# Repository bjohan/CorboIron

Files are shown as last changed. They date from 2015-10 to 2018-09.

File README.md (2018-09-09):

# CorboIron
With stand taken off
Soldering station with one pencil holder on bench.

Soldering station front view
Soldering station with both pencil holders hanging.

Soldering station side view
Side view

Front view again
Front view

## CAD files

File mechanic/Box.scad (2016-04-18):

module powerSupply()
{
    cube([200, 100, 42]);
}

module bottomHousing(ix, iy, iz, t)
{
    difference(){
        translate([-t,-t,-t])
            cube([ix+2*t, iy+2*t, iz+t]);
    
        cube([ix, iy, iz+1]);
    }
}

module iecHoles(t)
{
    hs = 55.5-3.5;
    lc = 23;
    
    rotate(-90, [0, 0, 1]){
    translate([0, lc-hs/2, 10])
        rotate(90,[0,1,0])
            cylinder(t, 3/2,3/2, $fn=10);
    translate([0, lc+hs/2, 10])
        rotate(90,[0,1,0])
            cylinder(t, 3/2,3/2, $fn=10);
    translate()
        cube([t, 46, 20]);
    }
}

module fanHoles(t)
{
    
    //translate([0, lc-hs/2, 10])
        rotate(90,[1,0,0]){
            cylinder(t, 24,24);
            translate([20, 20, 0])
                cylinder(t, 3/2, 3/2, $fn=10);
            translate([20, -20, 0])
                cylinder(t, 3/2, 3/2, $fn=10);
            translate([-20, 20, 0])
                cylinder(t, 3/2, 3/2, $fn=10);
            translate([-20, -20, 0])
                cylinder(t, 3/2, 3/2, $fn=10);
        }
}


module exhaustHoles(t)
{
    r = 2.5;
    sep = 10;
    for(x = [0:5])
        for (z = [0:2]){
            translate([x*sep, 0, z*sep])
                rotate(90,[1,0,0])
                    cylinder(t, r, r);
        }
        /*rotate(90,[1,0,0]){
            cylinder(t, 24,24);
            translate([20, 20, 0])
                cylinder(t, 3/2, 3/2);
            translate([20, -20, 0])
                cylinder(t, 3/2, 3/2);
            translate([-20, 20, 0])
                cylinder(t, 3/2, 3/2);
            translate([-20, -20, 0])
                cylinder(t, 3/2, 3/2);
        }*/
}



module bottomSectionHoles(ix, iy, iz, t,r){
    translate([-t-1, 10, iz-5])
        rotate(90, [0, 1, 0] )
            cylinder(ix+2*t+2, r);
    
    translate([-t-1, iy+2*t-10, iz-5])
        rotate(90, [0, 1, 0] )
            cylinder(ix+2*t+2, r);
    
    translate([-t-1, (iy+2*t)/2, iz-5])
        rotate(90, [0, 1, 0] )
            cylinder(ix+2*t+2, r);
}


module bottomSection(ix, iy, iz, t){ 
    difference(){
        bottomHousing(ix, iy, iz,t);
        translate([ix-30, iy+2*t-1, 24+2])
            fanHoles(6);
        translate([ix-120, iy+2*t-1, 0])
            iecHoles(6);
        translate([10, 1, 10])
            exhaustHoles(5, $fn=10);
         translate([ix-135, -4, -t]){
             displayCavity(55, 55, 135+t, t, 6);    
         }
         
          translate([75, -40, 5])
            rotate(45,[1,0,0]) 
                       translate([0,0,0])
            displayHoles(10, 3);
         
         
        /*translate([-3, 10, 40])
            iecHoles(3);
        translate([-4, 85, 60])
            fanHoles(6);*/
         bottomSectionHoles(ix, iy, iz, t, 3/2, $fn=10);

    }
   
   difference(){ 
    translate([ix-135, 0, -t]){
        displaySection(55, 55, 135+t, t);
    }
    
    translate([75, -40, 5])
        rotate(45,[1,0,0]){ 
            display();
            translate([0,0,0])
            displayHoles(10, 3/2);
            translate([115, 30, 0])
            cylinder(10, 7/2, 7/2);
        }
         translate([ix-135-1, -60, -3])
            cube([135+t+2,15,100]);
    }
    translate([ix-135, -45, -t])
            cube([135+t,t,10]);
   
}


module displayHoles(t, r)
{
    $fn = 10;
    y = 55;
    x = 93;
    xo = (98-x)/2;
    yo = (60-y)/2;
    translate( [xo,yo, 0])
        cylinder(t, r, r);
    translate( [xo+x,yo, 0])
        cylinder(t, r, r);
    translate( [xo+x,yo+y, 0])
        cylinder(t, r, r);
    translate( [xo,yo+y, 0])
        cylinder(t, r, r);
}

module displayVolumes(){
    cube([98, 60, 2]);
    translate([0, 10, -2])
        cube([98, 40, 14]);
    translate([8, 60-22, -12])
        cube([52, 22, 12]);
}


module displaySection(ox, oy,oz, t)
{
    oPoints = [[0, 0], [ox, 0], [0, oy]];
    iPoints = [[t, 0], [ox-t, 0], [t, oy-2*t]];
    rotate(180, [0, 0, 1])
    rotate(-90, [0, 1, 0])
    difference(){
        linear_extrude(oz)
            polygon(oPoints);
    
        translate([0,0,t])
            linear_extrude(oz-2*t)
                polygon(iPoints);
    }
}

module displayCavity(ox, oy, oz, td, t)
{
    x = ox-2*td;
    y = oy -2*td;
    z = oz -2*td;
    translate([td, 0, td])
    cube([z,t, x]);
}


module display()
{
    difference(){
        displayVolumes();
        translate([0,0,-1])
        displayHoles(5);
    }
    
}


module pcb(){
    cube([160, 100, 2]);
    translate([-20, 4, 2])
        cube([20, 92, 17]);
}

module topHousing(ix, iy, iz, t, tol, overlap, height){
 translate([t+tol/2, t+tol/2, iz-overlap+t])
    bottomHousing(ix-tol-2*t, iy-tol-2*t, overlap-t, t);
    
 translate([0, 0, iz]){
     //difference(){
        translate([tol/2, tol/2, 0]){
            difference(){
            bottomHousing(ix-tol, iy-tol, height, t+tol/2);
            translate([0,0,-t-tol])
                cube([ix-tol, iy-tol, t+tol]);
            }
        }
     //}
     translate([1,7,-8])
     difference(){
        cube([10,15,10]);
         translate([5, 5, 0])
            cylinder(10, 1.5, 1.5, $fn=10);
     }
     translate([150,7,-8])
     difference(){
        cube([15,15,10]);
         translate([7, 5, 0])
            cylinder(10, 1.5, 1.5, $fn=10);
     }
     translate([1, 100, 0]){
         translate([0,5,-8])
             difference(){
                cube([10,15,10]);
                 translate([5, 10, 0])
                    cylinder(10, 1.5, 1.5, $fn=10);
             }
         translate([150,5,-8])
             difference(){
                cube([15,15,10]);
                 translate([7, 10, 0])
                    cylinder(10, 1.5, 1.5, $fn=10);
             }
     }
 }
    }

module topSection(ix, iy, iz, t, tol, overlap, height){

    difference(){
    topHousing(ix, iy, iz, t, tol, overlap, height);
        translate([t+tol/2, t+tol/2, iz-overlap+t]){
    translate([-t,10,8]){
        pcb();
        translate([151-t-tol/2, 113+t-5, -overlap-t])
            cube([50, 20, overlap+t]);
    }
     
    }bottomSectionHoles(ix, iy, iz, t, 3/2, $fn=10);
    }
    //translate to bottom plane
    translate([t+tol/2, t+tol/2, iz-overlap+t]){
        translate([-t-tol/2,0,8]){
            //pcb();
        }
        translate([-t*2-tol/2, -t*2-tol/2, -t])
            difference(){
                cube([ix+t*2, iy+t*2, overlap+t]);
                    translate([0.5, 0.5, 0])
                        cube([ix+t*2-1, iy+t*2-1, overlap+t]);
            }
    }
    
}


//displayHoles(20, 3/2);
ix = 201;
iy = 145;
iz = 55;
t = 3;
tol = 1;
overlap = 10;
height = 20;

//bottomSection(ix, iy, iz, t);
topSection(ix, iy, iz, t, tol, overlap, height);
module bottomSupports(){
translate([100, -8, 0])
cylinder(42.2,3,3);
translate([140, -8, 0])
cylinder(42.2,3,3);
translate([105, iy, 0])
cylinder(19.9,3,3);
}
//translate([75, -40, 5])
//        rotate(45,[1,0,0]) 
//            display();

//translate([-3, 10, 40])
//        iecHoles(3);
//translate([-4, iy+2*t, 60])
//        fanHoles(6);
//translate([0,15,0])
//    powerSupply();

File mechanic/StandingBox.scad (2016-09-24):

//$fn=200;
mainHousingInsideX = 120;
mainHousingInsideY = 120;
mainHousingInsideZ = 210;
t = 3;

dispTiltOffs = 20;
dispProjHeight = 50;
dispRecess = 40;
topFoldHeight = 20;

module powerSupply()
{
    cube([200, 100, 42]);
}

module iecHoles(t)
{
    hs = 55.5-3.5;
    lc = 23;
    
    rotate(-90, [0, 0, 1]){
    translate([0, lc-hs/2, 10])
        rotate(90,[0,1,0])
            cylinder(t, 3/2,3/2, $fn=10);
    translate([0, lc+hs/2, 10])
        rotate(90,[0,1,0])
            cylinder(t, 3/2,3/2, $fn=10);
    translate()
        cube([t, 46, 20]);
    }
}

module fanHoles(t)
{
    
    //translate([0, lc-hs/2, 10])
        rotate(90,[1,0,0]){
            cylinder(t, 24,24);
            translate([20, 20, 0])
                cylinder(t, 3/2, 3/2, $fn=10);
            translate([20, -20, 0])
                cylinder(t, 3/2, 3/2, $fn=10);
            translate([-20, 20, 0])
                cylinder(t, 3/2, 3/2, $fn=10);
            translate([-20, -20, 0])
                cylinder(t, 3/2, 3/2, $fn=10);
        }
}


module displayHoles(t, r)
{
    $fn = 10;
    y = 55;
    x = 93;
    xo = (98-x)/2;
    yo = (60-y)/2;
    translate( [xo,yo, 0])
        cylinder(t, r, r);
    translate( [xo+x,yo, 0])
        cylinder(t, r, r);
    translate( [xo+x,yo+y, 0])
        cylinder(t, r, r);
    translate( [xo,yo+y, 0])
        cylinder(t, r, r);
}

module displayVolumes(){
    cube([98, 60, 2]);
    translate([0, 10, -2])
        cube([98, 40, 14]);
    translate([8, 60-22, -12])
        cube([52, 22, 12]);
}




module display()
{
    difference(){
        displayVolumes();
        translate([0,0,-1])
        displayHoles(5);
    }
    
}


module pcb(){
    cube([160, 100, 2]);
    translate([-20, 4, 2])
        cube([20, 92, 17]);
}

module mainHousing(sx, sy, sz, t){
    fanHoleY=70;
    fanHoleZ=30;
    exhaustSeparation = 10;
    difference(){
        cube([sx, sy, sz]);
        translate([t, t, t])
            cube([sx-2*t, sy-t+1, sz-2*t]);
        translate([sx/2, sy/2+10, sz+1])
            rotate([90, 0, 0])
                fanHoles(t+2);    
        for(n = [0:15]){
            translate([sx-t-1, 20+t, 20+t+exhaustSeparation*n])
                rotate([0, 90, 0])
                    cylinder(t+2, 2.5, 2.5);
        }
    }
    
}

module mainHousingFrontPanelScrewHoles(sx, sy, sz, t){
    translate([t+10, sy+t, t+5]){
        for(n = [0:5]){
            translate([20*n, 0, 0])
                rotate([90, 0, 0])
                    cylinder(25, 1.5, 1.5);
        }
    }
    
        translate([t+10, sy+t, sz-t-5]){
        for(n = [0:5]){
            translate([20*n, 0, 0])
                rotate([90, 0, 0])
                    cylinder(25, 1.5, 1.5);
        }
    }
}


module mainHousingWithFrontPanelHoles(sx, sy, sz, t){
    difference(){
        union(){
            mainHousing(sx, sy, sz, t);
            translate([t, sy-10-t, t])
                cube([sx-2*t, 10,10]);
            translate([t, sy-10-t, sz-10-t])
                cube([sx-2*t, 10,10]);
            
        }
        mainHousingFrontPanelScrewHoles(sx, sy, sz, t);
    }
}

function getDispAngle() =
    atan2(dispProjHeight, dispRecess);

module frontPanelOnSide(height, width, t){
    //dispTiltOffs = 10;
    //dispProjHeight = 50;
    //dispRecess = 30;
    //topFoldHeight = 20;http://www.di.se/artiklar/2016/6/5/schweiz-rostar-om-medborgarlon/
    dto = dispTiltOffs;
    poly = [    [0,0],
                [dispTiltOffs,0],
                [dispProjHeight+dto,dispRecess],
                //[height,dispRecess],
                [height-topFoldHeight, dispRecess],
                [height-topFoldHeight, 0],
                [height, 0],
                [height, t],
                [height-topFoldHeight+t, t],
                
                [height-topFoldHeight+t,dispRecess+t],
    
                //[height,dispRecess+t],
                [dispProjHeight+dto,dispRecess+t],
                [dispTiltOffs,+t],
                [0,t]];
    linear_extrude(width)
        polygon(points=poly);
    
}

module placedFrontPanel(height, width, depth, t){
    /*t = 3;

dispTiltOffs = 20;
dispProjHeight = 50;
dispRecess = 40;
topFoldHeight = 20;*/
    translate([t, depth+t, t])
    
    rotate([0, -90, 180]){
        frontPanelOnSide(height, width, t);
        translate([dispProjHeight+dispTiltOffs, dispRecess+t,0])
            cube([10, 10, width]);
        translate([height-topFoldHeight-10+t, dispRecess+t,0])
            cube([10, 10, width]);
    }
}

module placedDisplay(){
translate([t+(mainHousingInsideX-98)/2, 78, 68])
    rotate(-getDispAngle(),[1, 0, 0])
        rotate([0, 0, 180])
            translate([-98,-60, 0]){
                display();
               
            }
}

module placedDisplayHoles(){
translate([t+(mainHousingInsideX-98)/2, 78, 68])
    rotate(-getDispAngle(),[1, 0, 0])
        rotate([0, 0, 180])
            translate([-98,-60, 0]){
                displayHoles(10, 3/2);
            }
}
        
module placedFrontPanelWithHoles(height, width, depth, t){
    difference(){
        placedFrontPanel(height, width, depth, t);
        placedDisplay();
        placedDisplayHoles();
        mainHousingFrontPanelScrewHoles(mainHousingInsideX+2*t, mainHousingInsideY+t, mainHousingInsideZ+2*t,t);
    }
}


module placedPowerSupply(t){
    translate([t, t, t])
        rotate([0,-90,-90])
            powerSupply();
}


module penHolderMainBody(frontAngle){
    length = 110;
    height = 35;
    width = mainHousingInsideX/2;
    //frontAngle = 40;
    difference(){
    cube([width, length, height]);
    translate([0, length, 0])
        rotate([frontAngle, 0, 0])
            cube(2*[height, height, height]);
    }
}

module penHolderWithPrintHoles(angle){
    dia = 11.8;
    difference(){
        penHolderMainBody(angle);
        translate([dia, 90+2.1, dia/2])
            rotate([angle, 0, 0])
                cylinder(100 , dia/2, dia/2);
        
        translate([mainHousingInsideX/2-dia, 90+2.1, dia/2])
            rotate([angle, 0, 0])
                cylinder(100 , dia/2, dia/2);
    }
}


module penHolderDryClean(angle){
    h = 35;
    dia = 56;
    d=55;
    dt = d+h;
    angle=20;
    hd = (dia/2+2)/sqrt(2);
    difference(){
        penHolderMainBody(angle);
        
        translate([mainHousingInsideX/4, dia/2+5, 10])
            rotate([angle, 0, 0]){
                cylinder(100 , dia/2-2, dia/2-2);
                translate([0,0,13])
                    cylinder(100 , dia/2, dia/2);
                translate([hd, hd, 0])
                    cylinder(100, 3/2, 3/2);
                translate([hd, -hd, 0])
                    cylinder(100, 3/2, 3/2);
                translate([-hd, hd, 0])
                    cylinder(100, 3/2, 3/2);
                translate([-hd, -hd, 0])
                    cylinder(100, 3/2, 3/2);
                
            }

    translate([0, d, h])
        rotate([angle, 0, 0])
            translate([0, -dt, 0]){
                cube([mainHousingInsideX/2, dt, 30]);
            }

    }
    
}


module penHolder(){
  
   
    //translate([0, 0, 30])
    
    intersection(){
        penHolderDryClean(0);
        penHolderWithPrintHoles(40);
    }
}


module printFrontPanel(){
    rotate([0, 90, 0])
    placedFrontPanelWithHoles(mainHousingInsideZ, mainHousingInsideX, mainHousingInsideY, t);
    translate([10, 120, -t-2])
        cylinder(2,20,20);
    translate([210, 120, -t-2])
        cylinder(2,20,20);
    translate([80, 120-40, -t-2])
        cylinder(2,20,20);
    translate([180, 120-40, -t-2])
        cylinder(2,20,20);
}

//printFrontPanel();

/*translate([0, 120, 0])
    penHolder();

translate([0, 73, 185])
    rotate([-90,0,0])
        penHolder();*/
mainHousingWithFrontPanelHoles(mainHousingInsideX+2*t, mainHousingInsideY+t, mainHousingInsideZ+2*t,t);

placedFrontPanelWithHoles(mainHousingInsideZ, mainHousingInsideX, mainHousingInsideY, t);

//placedPowerSupply(t);

//placedDisplay();

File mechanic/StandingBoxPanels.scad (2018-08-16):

//$fn=200;
mainHousingInsideX = 120;
mainHousingInsideY = 120;
mainHousingInsideZ = 210;
t = 3;

dispTiltOffs = 20;
dispProjHeight = 50;
dispRecess = 40;
topFoldHeight = 20;


module iecHoles(t){
    hs = 55.5-3.5;
    lc = 23;
    
    rotate(-90, [0, 0, 1]){
    translate([0, lc-hs/2, 10])
        rotate(90,[0,1,0])
            cylinder(t, 3/2,3/2, $fn=10);
    translate([0, lc+hs/2, 10])
        rotate(90,[0,1,0])
            cylinder(t, 3/2,3/2, $fn=10);
    translate()
        cube([t, 46, 20]);
    }
}

module fanHoles(t){
    
    //translate([0, lc-hs/2, 10])
        //rotate(90,[1,0,0]){
            cylinder(t, 24,24);
            translate([20, 20, 0])
                cylinder(t, 3/2, 3/2, $fn=10);
            translate([20, -20, 0])
                cylinder(t, 3/2, 3/2, $fn=10);
            translate([-20, 20, 0])
                cylinder(t, 3/2, 3/2, $fn=10);
            translate([-20, -20, 0])
                cylinder(t, 3/2, 3/2, $fn=10);
        //}
}


module displayHoles(t, r){
    $fn = 10;
    y = 55;
    x = 93;
    xo = (98-x)/2;
    yo = (60-y)/2;
    translate( [xo,yo, 0])
        cylinder(t, r, r);
    translate( [xo+x,yo, 0])
        cylinder(t, r, r);
    translate( [xo+x,yo+y, 0])
        cylinder(t, r, r);
    translate( [xo,yo+y, 0])
        cylinder(t, r, r);
}

module displayVolumes(){
    cube([98, 60, 2]);
    translate([0, 10, -2])
        cube([98, 40, 14]);
    translate([8, 60-22, -12])
        cube([52, 22, 12]);
}




module display(){
    difference(){
        displayVolumes();
        translate([0,0,-1])
        displayHoles(5);
    }
    
}


module pcb(){
    cube([100, 80, 2]);
    //Iron 0 iron 1 connector
    translate([1, -5, 2])
        cube([31, 12, 11]);
    
    //Iron 2 and iron 3 connector
    translate([100-1-31, -5, 2])
        cube([31, 12, 11]);
    
    //Power in at bottom connector
    translate([43, 3, -20])
        cube([12, 25, 20]);
    
    //Filter and voltage regulator volume
    translate([37, 2, 2])
        cube([30, 30, 20]);
    
    //Arduino volume
    translate([41, 27, 2])
        cube([18, 45, 22]);
    
    //Pin headers
    translate([35, 42, 2])
        cube([3, 30, 20]);
    translate([53, 70, 2])
        cube([11, 3, 20]);
        
    //Capacitors
    translate([12, 66, 2])    
        cylinder(13,4,4);
    translate([23, 66, 2])    
        cylinder(13,4,4);
    translate([77, 66, 2])    
        cylinder(13,4,4);
    translate([89, 66, 2])    
        cylinder(13,4,4);
    
}

module mainHousing(sx, sy, sz, t){
    fanHoleY=70;
    fanHoleZ=30;
    exhaustSeparation = 10;
    difference(){
        cube([sx, sy, sz]);
        translate([t, t, t])
            cube([sx-2*t, sy-t+1, sz-2*t]);
        translate([sx/2, sy/2+10, sz+1])
            rotate([90, 0, 0])
                fanHoles(t+2);    
        for(n = [0:15]){
            translate([sx-t-1, 20+t, 20+t+exhaustSeparation*n])
                rotate([0, 90, 0])
                    cylinder(t+2, 2.5, 2.5);
        }
    }
    
}

module mainHousingFrontPanelScrewHoles(sx, sy, sz, t){
    translate([t+10, sy+t, t+5]){
        for(n = [0:5]){
            translate([20*n, 0, 0])
                rotate([90, 0, 0])
                    cylinder(25, 1.5, 1.5);
        }
    }
    
        translate([t+10, sy+t, sz-t-5]){
        for(n = [0:5]){
            translate([20*n, 0, 0])
                rotate([90, 0, 0])
                    cylinder(25, 1.5, 1.5);
        }
    }
}


module mainHousingWithFrontPanelHoles(sx, sy, sz, t){
    difference(){
        union(){
            mainHousing(sx, sy, sz, t);
            translate([t, sy-10-t, t])
                cube([sx-2*t, 10,10]);
            translate([t, sy-10-t, sz-10-t])
                cube([sx-2*t, 10,10]);
            
        }
        mainHousingFrontPanelScrewHoles(sx, sy, sz, t);
    }
}

function getDispAngle() =
    atan2(dispProjHeight, dispRecess);

module frontPanelOnSide(height, width, t){
    //dispTiltOffs = 10;
    //dispProjHeight = 50;
    //dispRecess = 30;
    //topFoldHeight = 20;http://www.di.se/artiklar/2016/6/5/schweiz-rostar-om-medborgarlon/
    dto = dispTiltOffs;
    poly = [    [0,0],
                [dispTiltOffs,0],
                [dispProjHeight+dto,dispRecess],
                //[height,dispRecess],
                [height-topFoldHeight, dispRecess],
                [height-topFoldHeight, 0],
                [height, 0],
                [height, t],
                [height-topFoldHeight+t, t],
                
                [height-topFoldHeight+t,dispRecess+t],
    
                //[height,dispRecess+t],
                [dispProjHeight+dto,dispRecess+t],
                [dispTiltOffs,+t],
                [0,t]];
    linear_extrude(width)
        polygon(points=poly);
    
}

module placedFrontPanel(height, width, depth, t){
    /*t = 3;

dispTiltOffs = 20;
dispProjHeight = 50;
dispRecess = 40;
topFoldHeight = 20;*/
    translate([t, depth+t, t])
    
    rotate([0, -90, 180]){
        frontPanelOnSide(height, width, t);
        translate([dispProjHeight+dispTiltOffs, dispRecess+t,0])
            cube([10, 10, width]);
        translate([height-topFoldHeight-10+t, dispRecess+t,0])
            cube([10, 10, width]);
    }
}

module placedDisplay(){
translate([t+(mainHousingInsideX-98)/2, 78, 68])
    rotate(-getDispAngle(),[1, 0, 0])
        rotate([0, 0, 180])
            translate([-98,-60, 0]){
                display();
               
            }
}

module placedDisplayHoles(){
translate([t+(mainHousingInsideX-98)/2, 78, 68])
    rotate(-getDispAngle(),[1, 0, 0])
        rotate([0, 0, 180])
            translate([-98,-60, 0]){
                displayHoles(10, 3/2);
            }
}
        
module placedFrontPanelWithHoles(height, width, depth, t){
    difference(){
        placedFrontPanel(height, width, depth, t);
        placedDisplay();
        placedDisplayHoles();
        mainHousingFrontPanelScrewHoles(mainHousingInsideX+2*t, mainHousingInsideY+t, mainHousingInsideZ+2*t,t);
    }
}

module powerSupply(){
    cube([200, 100, 42]);
}


module placedPowerSupply(t){
    translate([10, 10, 3+200])
        rotate([0,90,0])
            powerSupply();
}


module penHolderMainBody(frontAngle){
    length = 110;
    height = 35;
    width = (mainHousingInsideX-2)/2;
    //frontAngle = 40;
    difference(){
    cube([width, length, height]);
    translate([0, length, 0])
        rotate([frontAngle, 0, 0])
            cube(2*[height, height, height]);
    }
}

module penHolderWithPrintHoles(angle){
    dia = 11.8;
    difference(){
        penHolderMainBody(angle);
        translate([dia, 90+2.1, dia/2])
            rotate([angle, 0, 0])
                cylinder(100 , dia/2, dia/2);
        
        translate([(mainHousingInsideX-2)/2-dia, 90+2.1, dia/2])
            rotate([angle, 0, 0])
                cylinder(100 , dia/2, dia/2);
    }
}


module penHolderDryClean(angle){
    h = 35;
    dia = 56;
    d=55;
    dt = d+h;
    angle=20;
    hd = (dia/2+2)/sqrt(2);
    difference(){
        penHolderMainBody(angle);
        
        translate([(mainHousingInsideX-2)/4, dia/2+5, 10])
            rotate([angle, 0, 0]){
                cylinder(100 , dia/2-2, dia/2-2);
                translate([0,0,13])
                    cylinder(100 , dia/2, dia/2);
                translate([hd, hd, 0])
                    cylinder(100, 3/2, 3/2);
                translate([hd, -hd, 0])
                    cylinder(100, 3/2, 3/2);
                translate([-hd, hd, 0])
                    cylinder(100, 3/2, 3/2);
                translate([-hd, -hd, 0])
                    cylinder(100, 3/2, 3/2);
                
            }

    translate([0, d, h])
        rotate([angle, 0, 0])
            translate([0, -dt, 0]){
                cube([(mainHousingInsideX-2)/2, dt, 30]);
            }
    }
    
}


module penHolder(){
    intersection(){
        penHolderDryClean(0);
        penHolderWithPrintHoles(40);
    }
}


module penHolderKnob(s){
    cylinder(5, s*30/2, s*35/2);
}

module penHolderKnobKeyHole(){
    hull(){
        penHolderKnob(1);
        translate([0,10,0])
            penHolderKnob(1.3);
    }
}

module truncatedPenHolder(){
    difference(){
    penHolder();
    translate([0,100,0])
        cube([100, 20, 20]);
    translate([0,85,0])
        cube([11,15,25]);
    translate([(mainHousingInsideX-2)/2-11,85,0])
        cube([11,15,25]);
    translate([(mainHousingInsideX-2)/4,40,0])
        penHolderKnobKeyHole();
    }
}
module printFrontPanel(){
    rotate([0, 90, 0])
    placedFrontPanelWithHoles(mainHousingInsideZ, mainHousingInsideX, mainHousingInsideY, t);
    translate([10, 120, -t-2])
        cylinder(2,20,20);
    translate([210, 120, -t-2])
        cylinder(2,20,20);
    translate([80, 120-40, -t-2])
        cylinder(2,20,20);
    translate([180, 120-40, -t-2])
        cylinder(2,20,20);
}



module multiPanelp(z){
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

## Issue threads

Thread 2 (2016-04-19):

Fix ground connection in 12V zones

bjohan, 2016-04-19:
The ground does look very good in the parts of the PCB which is covered by 12V zones

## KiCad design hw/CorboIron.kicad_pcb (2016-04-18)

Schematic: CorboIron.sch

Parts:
C1, C4, C5, C6: 1uF; CV3-30PF
C2: 4u7; CV3-30PF
C3: 220u; CV3-30PF
C7, C10: 100u; CV3-30PF
C8, C9: 10n; C_1206_HandSoldering
D1, D3, D4, D5, D7, D9, D11, D12, D13, D14: D; SOD-123
D2, D6, D8, D10: LED; LED_1206
JP1, JP2: Jumper_NO_Small; Pin_Header_Straight_1x02
P1, P2, P3, P5: CONN_01X03; bornier3
P4: Arduino_nano; DIP-32_W15.24mm_LongPads
P6, P10, P11: CONN_01X04; Pin_Header_Straight_1x04
P7: CONN_01X02; bornier2
P8, P9: CONN_01X03; Pin_Header_Straight_1x03
Q1, Q2, Q3, Q4: IPS6041RPBF; DPAK5
R1, R5, R9, R13, R17, R18, R19, R20, R21, R22, R23: 100K; R_0805
R2, R6, R10, R14: 680K; R_0805
R3, R28, R29: 4k7; R_0805
R4, R8, R12, R16: 1K; R_0805
R7, R11, R15, R34, R35, R40, R41, R46, R47: 4K7; R_0805
R24, R30, R36, R42: 22K; R_0805
R25, R31, R37, R43: 6K8; R_0805
R26, R32, R38, R44: 150K; R_0805
R27, R33, R39, R45: 2K7; R_0805
R48, R49, R50, R51: 27K; R_0805
RV1, RV3, RV5, RV7: 5K; POT_SMD
U1, U2, U3, U4: LM324; SO14N
U14: 7805; TO-220_Neutral123_Vertical

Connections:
+5V: C9.1, C10.1, JP1.2, P6.1, P8.2, P9.2, P11.1, R3.1, R7.1, R11.1, R15.1, R21.1, R22.1, R23.1, R29.1, R35.1, R41.1, R47.1, U14.3 (VO)
+12V: C7.1, C8.1, JP2.1, P7.2, Q1.3 (VCC), Q2.3 (VCC), Q3.3 (VCC), Q4.3 (VCC), R1.2, R5.2, R9.2, R13.2, RV1.1, RV3.1, RV5.1, RV7.1, U1.4, U2.4, U3.4, U4.4, U14.1 (VI)
/5V_ARD: JP1.1, P4.12
/AUX0: P4.6, P8.1
/AUX1: P4.7, P9.1
/CHARGE_PUMP: C2.1, P4.29
/HTR0_CTL': D14.2 (A), U4.1
/HTR0_EN: P4.27, R42.2
/HTR1_CTL: D13.2 (A), U3.1
/HTR1_EN: P4.26, R36.2
/HTR2_CTL: D12.2 (A), U2.1
/HTR2_EN: P4.25, R30.2
/HTR3_CTL: D11.2 (A), U1.1
/HTR3_EN: P4.24, R24.2
/PUSH_SW: P4.28, P10.1, R21.2
/ROT_A: P4.22, P10.2, R22.2
/ROT_B: P4.23, P10.3, R23.2
/RX0: P4.19, P11.2
/SCL: P4.9, P6.2
/SDA: P4.8, P6.3
/TEMP0: P5.2, U4.5
/TEMP0_AMP: P4.4, R14.2, U4.7, U4.12
/TEMP0_MIN: C6.1, D9.2 (A), R13.1, U4.9, U4.13
/TEMP0_OK: D10.1 (K), R20.2, R44.2, U4.8
/TEMP1: P3.2, U3.5
/TEMP1_AMP: P4.5, R10.2, U3.7, U3.12
/TEMP1_MIN: C5.1, D7.2 (A), R9.1, U3.9, U3.13
/TEMP1_OK: D8.1 (K), R19.2, R38.2, U3.8
/TEMP2: P2.2, U2.5
/TEMP2_AMP: P4.10, R6.2, U2.7, U2.12
/TEMP2_MIN: C4.1, D5.2 (A), R5.1, U2.9, U2.13
/TEMP2_OK: D6.1 (K), R18.2, R32.2, U2.8
/TEMP3: P1.2, U1.5
/TEMP3_AMP: P4.11, R2.2, U1.7, U1.12
/TEMP3_MIN: C1.1, D1.2 (A), R1.1, U1.9, U1.13
/TEMP3_OK: D2.1 (K), R17.2, R26.2, U1.8
/TX1: P4.18, P11.3
/VIN: JP2.2, P4.15
/V_NEG: C3.2, D3.2 (A), U1.11, U2.11, U3.11, U4.11
GND: C1.2, C3.1, C4.2, C5.2, C6.2, C7.2, C8.2, C9.2, C10.2, D4.1 (K), P1.3, P2.3, P3.3, P4.14, P4.21, P5.3, P6.4, P7.1, P8.3, P9.3, P10.4, P11.4, Q1.1 (GND), Q1.4 (DG), Q2.1 (GND), Q2.4 (DG), Q3.1 (GND), Q3.4 (DG), Q4.1 (GND), Q4.4 (DG), R4.1, R8.1, R12.1, R16.1, R27.1, R28.2, R33.1, R34.2, R39.1, R40.2, R45.1, R46.2, R48.1, R49.1, R50.1, R51.1, RV1.3, RV3.3, RV5.3, RV7.3, U14.2 (GND)
unnamed: C2.2, D3.1 (K), D4.2 (A)
unnamed: D1.1 (K), U1.14
unnamed: D2.2 (A), R3.2
unnamed: D5.1 (K), U2.14
unnamed: D6.2 (A), R7.2
unnamed: D7.1 (K), U3.14
unnamed: D8.2 (A), R11.2
unnamed: D9.1 (K), U4.14
unnamed: D10.2 (A), R15.2
unnamed: D11.1 (K), R25.2
unnamed: D12.1 (K), R31.2
unnamed: D13.1 (K), R37.2
unnamed: D14.1 (K), R43.2
unnamed: P1.1, Q1.5 (OUT)
unnamed: P2.1, Q2.5 (OUT)
unnamed: P3.1, Q3.5 (OUT)
unnamed: P4.1, R17.1
unnamed: P4.30, R20.1
unnamed: P4.31, R19.1
unnamed: P4.32, R18.1
unnamed: P5.1, Q4.5 (OUT)
unnamed: Q1.2 (IN), R25.1, R27.2
unnamed: Q2.2 (IN), R31.1, R33.2
unnamed: Q3.2 (IN), R37.1, R39.2
unnamed: Q4.2 (IN), R43.1, R45.2
unnamed: R2.1, R4.2, U1.6
unnamed: R6.1, R8.2, U2.6
unnamed: R10.1, R12.2, U3.6
unnamed: R14.1, R16.2, U4.6
unnamed: R24.1, R26.1, R48.2, U1.3
unnamed: R28.1, R29.2, U1.2
unnamed: R30.1, R32.1, R49.2, U2.3
unnamed: R34.1, R35.2, U2.2
unnamed: R36.1, R38.1, R50.2, U3.3
unnamed: R40.1, R41.2, U3.2
unnamed: R42.1, R44.1, R51.2, U4.3
unnamed: R46.1, R47.2, U4.2
unnamed: RV1.2, U1.10
unnamed: RV3.2, U2.10
unnamed: RV5.2, U3.10
unnamed: RV7.2, U4.10

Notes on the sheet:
Arduino Nano
OVER HEAT 0
D10
D11
D12
DISP_I2C
Rotary encoder with push button
OVER HEAT 1
OVER HEAT 2
OVER HEAT 3
D13
SERIAL
Add fan control!!!!
RST
High value current limiting resistor because negative supply rail is low current

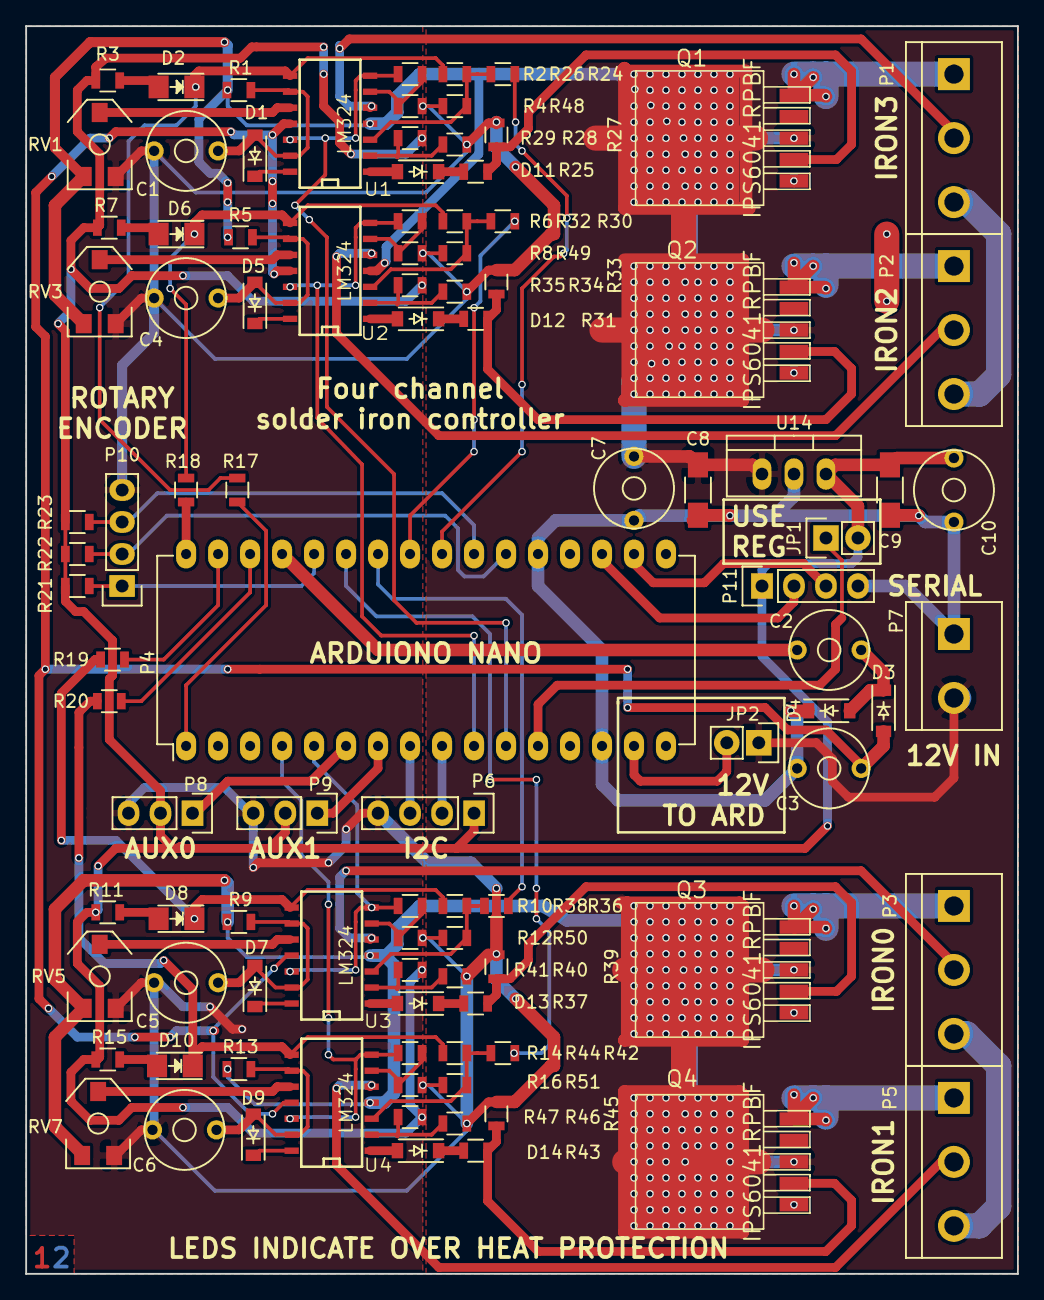
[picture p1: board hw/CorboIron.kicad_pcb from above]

Board: 2 copper layers, 78.7 x 99.1 mm, 101 parts (0 on the bottom side), 81 nets.

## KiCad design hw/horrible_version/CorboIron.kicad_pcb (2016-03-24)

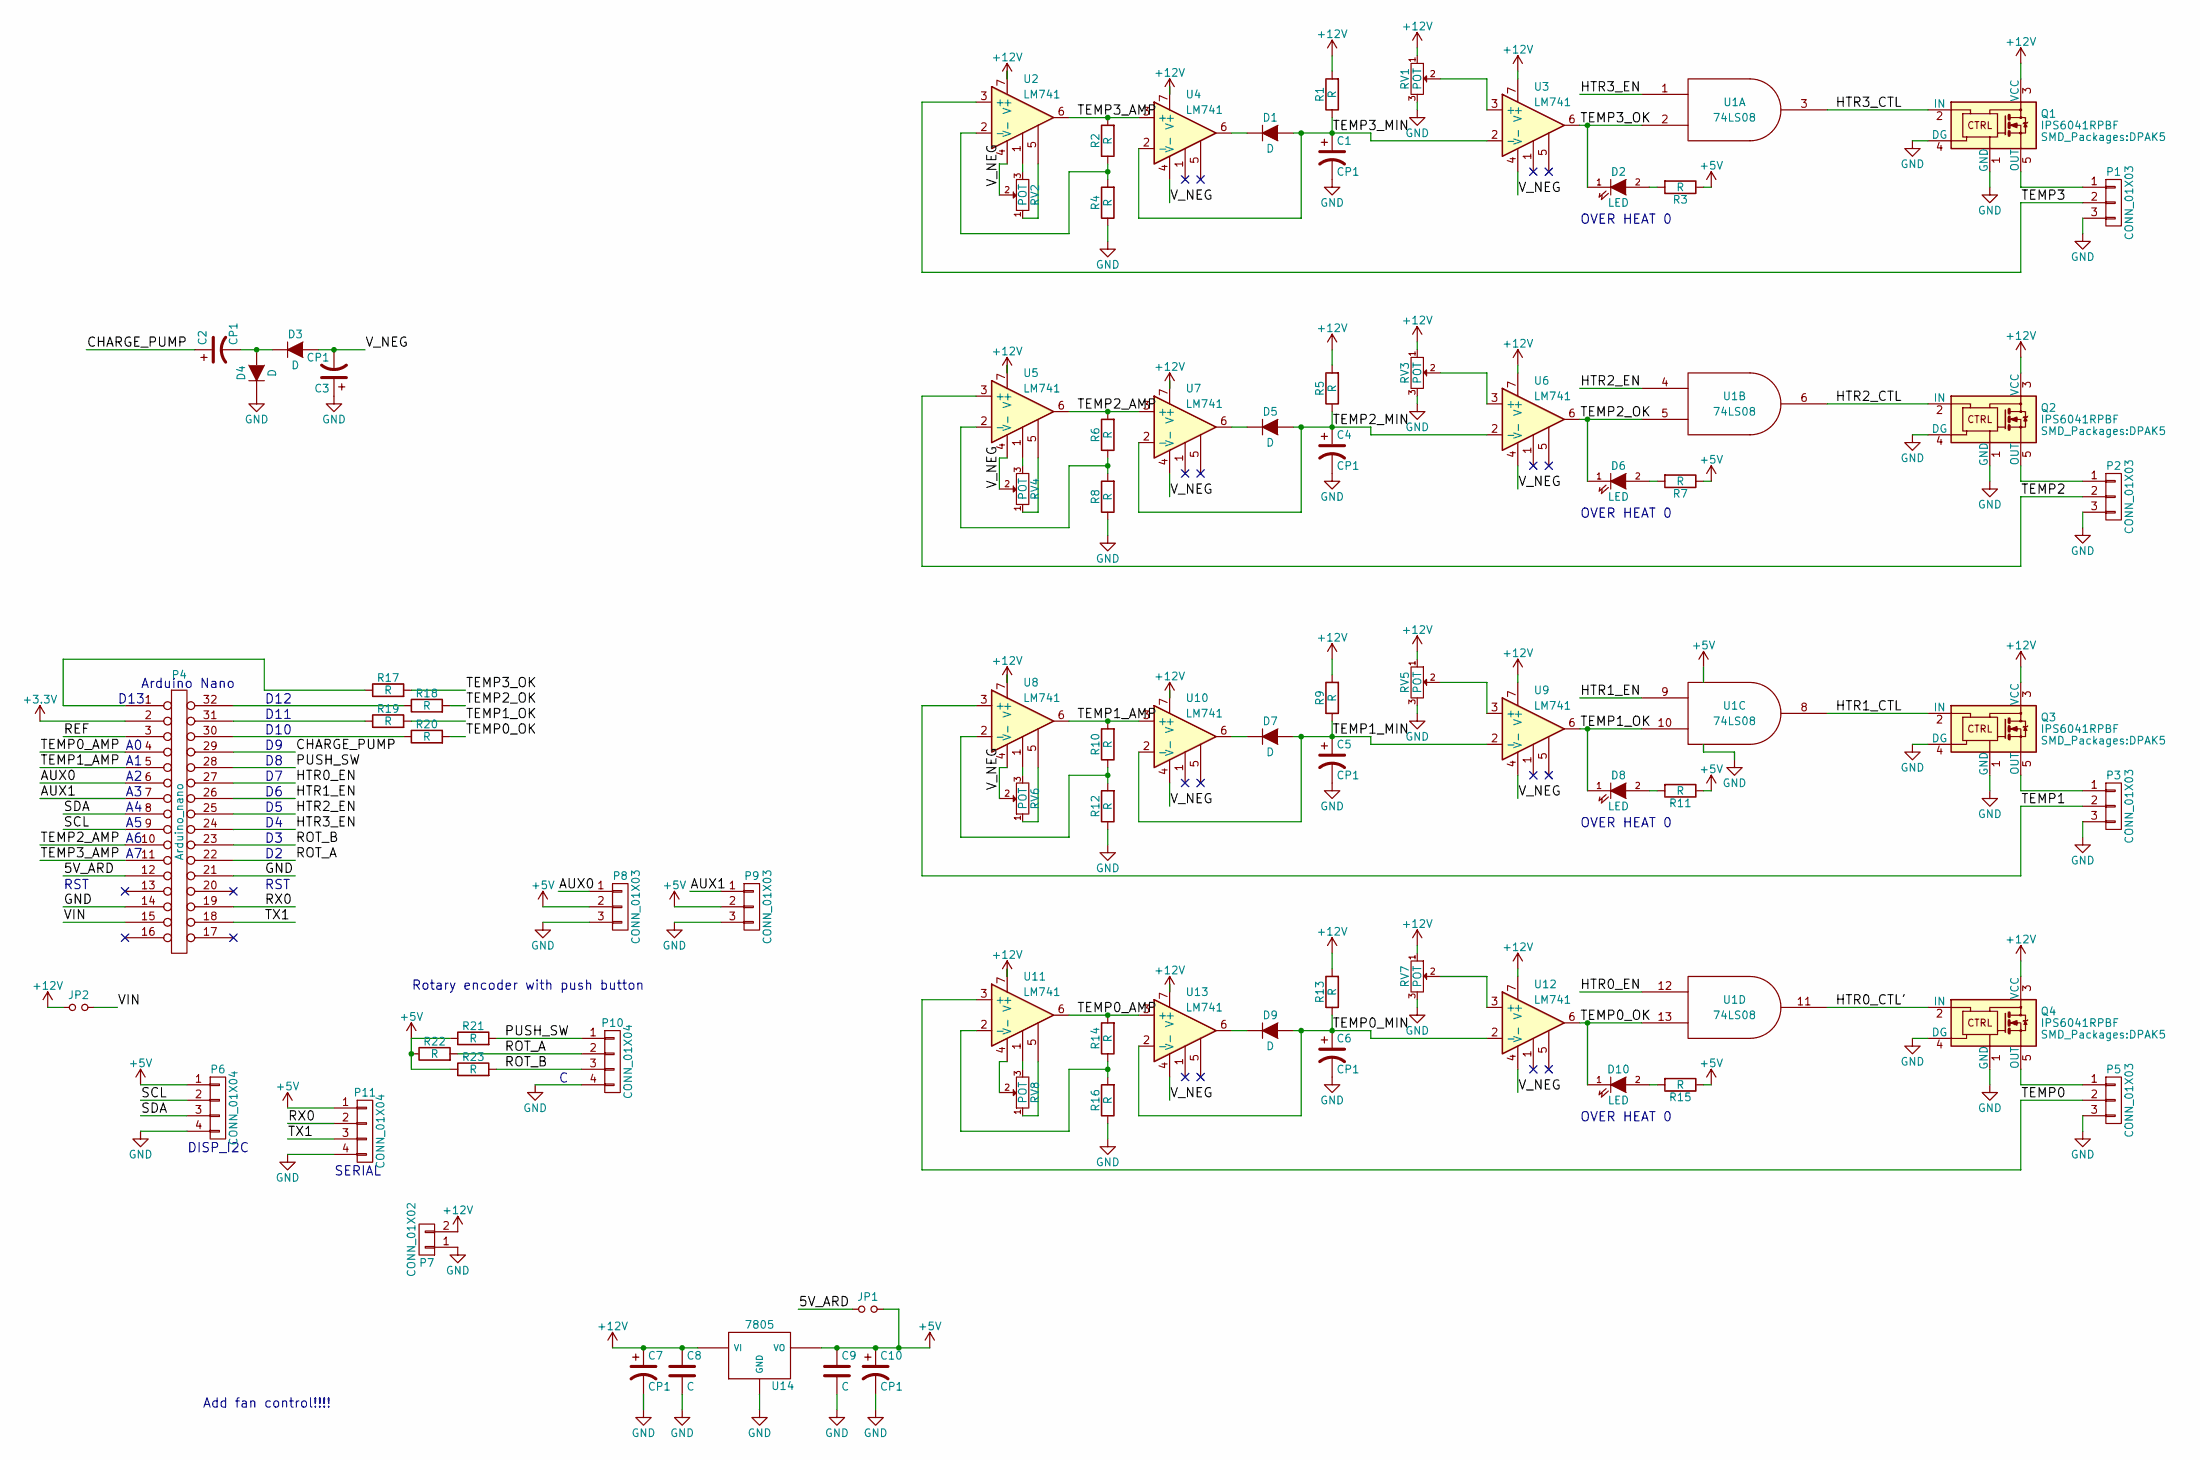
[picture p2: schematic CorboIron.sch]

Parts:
C1, C2, C3, C4, C5, C6, C7, C10: CP1; CV3-30PF
C8, C9: C; C_1206_HandSoldering
D1, D3, D4, D5, D7, D9: D; DO-214BA
D2, D6, D8, D10: LED; LED_1206
JP1, JP2: Jumper_NO_Small; Pin_Header_Straight_1x02
P1, P2, P3, P5: CONN_01X03; bornier3
P4: Arduino_nano
P6, P10, P11: CONN_01X04; Pin_Header_Straight_1x04
P7: CONN_01X02; bornier2
P8, P9: CONN_01X03; Pin_Header_Straight_1x03
Q1, Q2, Q3, Q4: IPS6041RPBF; DPAK5
R1, R2, R3, R4, R5, R6, R7, R8, R9, R10, R11, R12, R13, R14, R15, R16, R17, R18, R19, R20, R21, R22, R23: R; R_1206_HandSoldering
RV1, RV2, RV3, RV4, RV5, RV6, RV7, RV8: POT; POT_SMD
U1: 74LS08; SOIC-14_3.9x8.7mm_Pitch1.27mm
U2, U3, U4, U5, U6, U7, U8, U9, U10, U11, U12, U13: LM741; SOIC-8-N
U14: 7805; TO-220_Neutral123_Vertical

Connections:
+5V: C9.1, C10.1, JP1.2, P6.1, P8.2, P9.2, P11.1, R3.1, R7.1, R11.1, R15.1, R21.1, R22.1, R23.1, U1.14 (VCC), U14.3 (VO)
+12V: C7.1, C8.1, JP2.1, P7.2, Q1.3 (VCC), Q2.3 (VCC), Q3.3 (VCC), Q4.3 (VCC), R1.2, R5.2, R9.2, R13.2, RV1.1, RV3.1, RV5.1, RV7.1, U2.7 (V+), U3.7 (V+), U4.7 (V+), U5.7 (V+), U6.7 (V+), U7.7 (V+), U8.7 (V+), U9.7 (V+), U10.7 (V+), U11.7 (V+), U12.7 (V+), U13.7 (V+), U14.1 (VI)
/5V_ARD: JP1.1, P4.12
/AUX0: P4.6, P8.1
/AUX1: P4.7, P9.1
/CHARGE_PUMP: C2.1, P4.29
/HTR0_CTL': Q4.2 (IN), U1.11
/HTR0_EN: P4.27, U1.12
/HTR1_CTL: Q3.2 (IN), U1.8
/HTR1_EN: P4.26, U1.9
/HTR2_CTL: Q2.2 (IN), U1.6
/HTR2_EN: P4.25, U1.4
/HTR3_CTL: Q1.2 (IN), U1.3
/HTR3_EN: P4.24, U1.1
/PUSH_SW: P4.28, P10.1, R21.2
/ROT_A: P4.22, P10.2, R22.2
/ROT_B: P4.23, P10.3, R23.2
/RX0: P4.19, P11.2
/SCL: P4.9, P6.2
/SDA: P4.8, P6.3
/TEMP0: P5.2, U11.3 (+)
/TEMP0_AMP: P4.4, R14.2, U11.6, U13.3 (+)
/TEMP0_MIN: C6.1, D9.2 (A), R13.1, U12.2 (-), U13.2 (-)
/TEMP0_OK: D10.1 (K), R20.2, U1.13, U12.6
/TEMP1: P3.2, U8.3 (+)
/TEMP1_AMP: P4.5, R10.2, U8.6, U10.3 (+)
/TEMP1_MIN: C5.1, D7.2 (A), R9.1, U9.2 (-), U10.2 (-)
/TEMP1_OK: D8.1 (K), R19.2, U1.10, U9.6
/TEMP2: P2.2, U5.3 (+)
/TEMP2_AMP: P4.10, R6.2, U5.6, U7.3 (+)
/TEMP2_MIN: C4.1, D5.2 (A), R5.1, U6.2 (-), U7.2 (-)
/TEMP2_OK: D6.1 (K), R18.2, U1.5, U6.6
/TEMP3: P1.2, U2.3 (+)
/TEMP3_AMP: P4.11, R2.2, U2.6, U4.3 (+)
/TEMP3_MIN: C1.1, D1.2 (A), R1.1, U3.2 (-), U4.2 (-)
/TEMP3_OK: D2.1 (K), R17.2, U1.2, U3.6
/TX1: P4.18, P11.3
/VIN: JP2.2, P4.15
/V_NEG: C3.2, D3.2 (A), RV2.2, RV4.2, RV6.2, U2.4 (V-), U3.4 (V-), U4.4 (V-), U5.4 (V-), U6.4 (V-), U7.4 (V-), U8.4 (V-), U9.4 (V-), U10.4 (V-), U12.4 (V-), U13.4 (V-)
GND: C1.2, C3.1, C4.2, C5.2, C6.2, C7.2, C8.2, C9.2, C10.2, D4.1 (K), P1.3, P2.3, P3.3, P4.14, P4.21, P5.3, P6.4, P7.1, P8.3, P9.3, P10.4, P11.4, Q1.1 (GND), Q1.4 (DG), Q2.1 (GND), Q2.4 (DG), Q3.1 (GND), Q3.4 (DG), Q4.1 (GND), Q4.4 (DG), R4.1, R8.1, R12.1, R16.1, RV1.3, RV3.3, RV5.3, RV7.3, U1.7 (GND), U14.2 (GND)
unnamed: C2.2, D3.1 (K), D4.2 (A)
unnamed: D1.1 (K), U4.6
unnamed: D2.2 (A), R3.2
unnamed: D5.1 (K), U7.6
unnamed: D6.2 (A), R7.2
unnamed: D7.1 (K), U10.6
unnamed: D8.2 (A), R11.2
unnamed: D9.1 (K), U13.6
unnamed: D10.2 (A), R15.2
unnamed: P1.1, Q1.5 (OUT)
unnamed: P2.1, Q2.5 (OUT)
unnamed: P3.1, Q3.5 (OUT)
unnamed: P4.1, R17.1
unnamed: P4.30, R20.1
unnamed: P4.31, R19.1
unnamed: P4.32, R18.1
unnamed: P5.1, Q4.5 (OUT)
unnamed: R2.1, R4.2, U2.2 (-)
unnamed: R6.1, R8.2, U5.2 (-)
unnamed: R10.1, R12.2, U8.2 (-)
unnamed: R14.1, R16.2, U11.2 (-)
unnamed: RV1.2, U3.3 (+)
unnamed: RV2.1, U2.5
unnamed: RV2.3, U2.1
unnamed: RV3.2, U6.3 (+)
unnamed: RV4.1, U5.5
unnamed: RV4.3, U5.1
unnamed: RV5.2, U9.3 (+)
unnamed: RV6.1, U8.5
unnamed: RV6.3, U8.1
unnamed: RV7.2, U12.3 (+)
unnamed: RV8.1, U11.5
unnamed: RV8.2, U11.4 (V-)
unnamed: RV8.3, U11.1

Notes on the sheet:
Arduino Nano
OVER HEAT 0
D10
D11
D12
DISP_I2C
Rotary encoder with push button
D13
SERIAL
Add fan control!!!!
RST

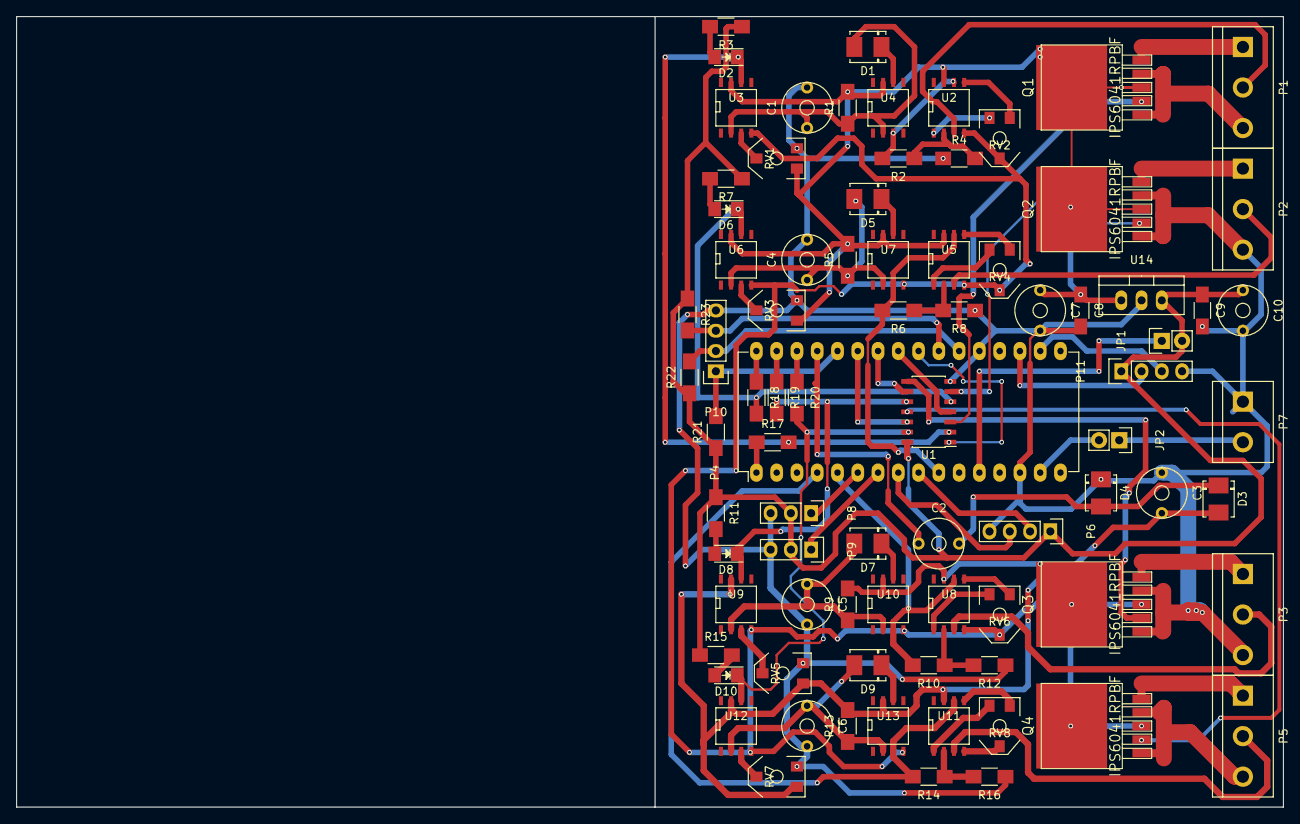
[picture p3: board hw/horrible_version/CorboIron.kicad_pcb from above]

Board: 2 copper layers, 158.8 x 99.1 mm, 82 parts (0 on the bottom side), 74 nets.

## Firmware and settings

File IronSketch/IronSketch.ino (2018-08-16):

#include <EEPROM.h>
#include <LiquidCrystal_I2C.h>
extern "C"
{
#include "uart_command_lib.h"
#include "corbomite.h"
}


#define SET_HEATER_TIP3 (PORTD |= (1 << 4))
#define CLEAR_HEATER_TIP3 (PORTD &= ~(1 << 4))

#define SET_HEATER_TIP2 (PORTD |= (1 << 5))
#define CLEAR_HEATER_TIP2 (PORTD &= ~(1 << 5))

#define SET_HEATER_TIP1 (PORTD |= (1 << 6))
#define CLEAR_HEATER_TIP1 (PORTD &= ~(1 << 6))

#define SET_HEATER_TIP0 (PORTD |= (1 << 7))
#define CLEAR_HEATER_TIP0 (PORTD &= ~(1 << 7))

#define encoder0PinA 2
#define encoder0PinB 3

enum buttonAction{NONE,PRESS, LONG_PRESS};

volatile int encoder0Pos = 0;

uint32_t vOffset[4] = {uint32_t(1.538*65536), uint32_t(0.013*65536), uint32_t(0.750*65536), uint32_t(0.154*65536)};
uint32_t gain[4] = {uint32_t(525)<<16, uint32_t(525)<<16, uint32_t(525)<<16, uint32_t(525)<<16};
int tempPins[] = {A0, A1, A6, A7};
int heaterPins[] = {7, 6, 5, 4};
int ch1TempPin = A0;
int chargePumpPin = 9;
int heaterPin = 7;
int heatLed = 13;
int heaterLevel = 200;
int rawAdcValue = 1024;
int setPoint = 0;
float sP;
float sI;
float sD;

volatile uint8_t skip_samp = 64;
volatile uint8_t over_samp = 64;
volatile int sampCount = 0;

struct menuState {
	uint8_t pressCount;
	uint8_t cursorChannel;
	uint8_t channelIsSelected;
};

struct tipState {
	uint32_t adc_value;
	uint32_t adc_value_target;
	uint8_t pwm_value;
	unsigned int temperature;
	unsigned int temperature_target;
};


//table in 16.16 for converting celcius to mV. One point every 32 C
const uint32_t tToV[19] = {0, 21430, 45377, 71631, 100008, 130286, 162293, 195861, 230818, 267059, 304349, 342688, 381852, 421737, 462291, 503382, 544932, 586901, 629159};

//table in 16.16 for converting mV to celcius. One point every 0.5 mV
const uint32_t vToT[21] =  {0, 3114410, 5820835, 8266898, 10538541, 12681425, 14725620, 16692405, 18593499, 20447232, 22253590, 24026343, 25767091, 27484160, 29178644, 30855147, 32513138, 34160640, 35797002, 37423651, 39043960};

volatile struct tipState ts[4] = {{0, 0, 0, 0, 0}, {0, 0, 0, 0, 0}, {0, 0, 0, 0, 0}, {0, 0, 0, 0, 0} };

LiquidCrystal_I2C lcd(0x27, 2, 1, 0, 4, 5, 6, 7, 3, POSITIVE);
extern "C" {
	void setSetPoint( int32_t temp)
	{
		setPoint = temp;
		ts[0].temperature_target = temp;
	}

	void setPParameter( int32_t temp)
	{
		sP = (float) temp/1000.0;
	}

	void setIParameter( int32_t temp)
	{
		sI = (float) temp/1000.0;
	}

	void setDParameter( int32_t temp)
	{
		sD = (float) temp/1000.0;
	}


	ANA_OUT("setPoint", "C", "0", "500", 0, 500, setSetPoint ,setPointTemperature);
	ANA_OUT("setP", "C", "0", "3", 0, 3000, setPParameter ,setPWidget);
	ANA_OUT("setI", "C", "0", "3", 0, 3000, setIParameter ,setIWidget);
	ANA_OUT("setD", "C", "0", "3", 0, 3000, setDParameter ,setDWidget);
	ANA_IN("temperature", "C", "0", "1023", 0, 1023, temperature);
	ANA_IN("power", "W", "0", "40", 0, 255, powerWidget);
	ANA_IN("ppower", "W", "0", "40", 0, 4000, pPowerWidget); 
	ANA_IN("ipower", "W", "0", "40", 0, 4000, iPowerWidget); 
	ANA_IN("dpower", "W", "0", "40", 0, 4000, dPowerWidget); 


	const CorbomiteEntry last PROGMEM = {LASTTYPE, "", 0};
	const EventData initEvent PROGMEM = {registeredEntries};

	const CorbomiteEntry initcmd PROGMEM = 
	{EVENT_OUT, internalId, (CorbomiteData*)&initEvent};

	const CorbomiteEntry * const entries[] PROGMEM = {
		&setPointTemperature,
		&setPWidget,
		&setIWidget,
		&setDWidget,
		&temperature,
		&powerWidget,
		&pPowerWidget,
		&iPowerWidget,
		&dPowerWidget,
		&initcmd, &last
	};


}

uint32_t millivoltsToCelcius(uint32_t mv){
	uint8_t idx = mv>>15;
	if(idx >= 20) return (uint32_t) 1000<<16;
	uint32_t base = vToT[idx];
	uint32_t delta = vToT[idx+1]-base;
	uint32_t frac = ((mv&((uint32_t)0x7fff)));
	uint32_t prod = (delta>>7)*(frac>>8);
	//Serial.print("Base ");Serial.print(base/65536.0);Serial.print(" delta ");Serial.print(delta/65536.0);
	//Serial.print(" frac ");Serial.print( (frac)/32768.0); Serial.print(" prod " ); Serial.println(prod/65536.0);
	//return base+(((mv&0x7FFF)*delta)>>14);
	return base+prod;
}

uint32_t celciusToMillivolts(uint32_t c){
	uint8_t idx = c >> (16+5);
	if(idx >=18) return (uint32_t)10<< 16;
	uint32_t base = tToV[idx];
	uint32_t delta = tToV[idx+1]-base;
	uint32_t frac = c&0x1fffff;
	uint32_t prod = (delta>>8)*(frac>>13);
	//Serial.print("Base ");Serial.print(base/65536.0);Serial.print(" delta ");Serial.print(delta/65536.0);
	//Serial.print(" frac ");Serial.print( (frac>>5)/65536.0); Serial.print(" prod " ); Serial.println(prod/65536.0);
	return base+prod;
}

uint32_t clamp(int32_t low, int32_t val, int32_t high){
	if(val < low) return low;
	if(val > high) return high;
	return val;
}

void initLcd(){
	lcd.begin(20,4);
	lcd.backlight();
	lcd.setCursor(0,0);
	/*lcd.print("Welcome to CorboIron");

	lcd.setCursor(0,2);
	lcd.print("Version 0.000");

	lcd.setCursor(0,3);
	for(int i = 0 ; i < 20 ; i++){
		lcd.print('-');
		delay(10);
	}
	lcd.setCursor(0,3);
	for(int i = 0 ; i < 20 ; i++){
		lcd.print(' ');
		delay(10);
	}
*/
}

void doEncoderA(){

	// look for a low-to-high on channel A
	if (digitalRead(encoder0PinA) == HIGH) { 

		// check channel B to see which way encoder is turning
		if (digitalRead(encoder0PinB) == LOW) {  
			encoder0Pos = encoder0Pos + 1;         // CW
		} 
		else {
			encoder0Pos = encoder0Pos - 1;         // CCW
		}
	}

	else   // must be a high-to-low edge on channel A                                       
	{ 
		// check channel B to see which way encoder is turning  
		if (digitalRead(encoder0PinB) == HIGH) {   
			encoder0Pos = encoder0Pos + 1;          // CW
		} 
		else {
			encoder0Pos = encoder0Pos - 1;          // CCW
		}
	}
	//Serial.println (encoder0Pos, DEC);          
	// use for debugging - remember to comment out

}

void doEncoderB(){

	// look for a low-to-high on channel B
	if (digitalRead(encoder0PinB) == HIGH) {   

		// check channel A to see which way encoder is turning
		if (digitalRead(encoder0PinA) == HIGH) {  
			encoder0Pos = encoder0Pos + 1;         // CW
		} 
		else {
			encoder0Pos = encoder0Pos - 1;         // CCW
		}
	}

	// Look for a high-to-low on channel B

	else { 
		// check channel B to see which way encoder is turning  
		if (digitalRead(encoder0PinA) == LOW) {   
			encoder0Pos = encoder0Pos + 1;          // CW
		} 
		else {
			encoder0Pos = encoder0Pos - 1;          // CCW
		}
	}

} 
#define K_t 0.0000160
#define M_t (-0.00096)

#define K_a 1200.0
#define M_a (-1.1)

#define K_c (1023.0/4.98)
#define M_c (-6.0)


#define K_tot (K_t*K_a*K_c)
#define M_tot (M_t*K_a*K_c + M_a*K_c + M_c)


void EepromRead(uint16_t address, uint16_t length, char *data){
	for(uint16_t a = address ; a < address+length ; a++){
		*data = EEPROM.read(a);
		data++;
	}
}

void EepromWrite(uint16_t address, uint16_t length, char *data){
	for(uint16_t a = address ; a < address+length ; a++){
		EEPROM.write(a, *data);
		data++;
	}
}

void loadChannel(uint8_t ch){
	EepromRead(ch*8+0, 4, (char*)&vOffset[ch]);
	EepromRead(ch*8+4, 4, (char*)&gain[ch]);
}

void saveChannel(uint8_t ch){
	EepromWrite(ch*8+0, 4, (char*)&vOffset[ch]);
	EepromWrite(ch*8+4, 4, (char*)&gain[ch]);
}

uint32_t tomV2(uint32_t v, uint8_t ch){
	return ((v*5>>10)*1000)/(gain[ch]>>16)+vOffset[ch];
}

uint32_t adcTomV(uint32_t adc, uint8_t ch){
	uint32_t v = (adc*5) >> 10; 
	uint32_t mv = v*1000;
	uint32_t gainCorr = (mv/(gain[ch]>>16));
	uint32_t offsetCorr = gainCorr+vOffset[ch];
	return offsetCorr;
}

uint32_t mvToAdc(uint32_t mvo, uint8_t ch){
	int32_t gainCorr = mvo -vOffset[ch];
	if(gainCorr < 0) return 0;
	uint32_t mv = gainCorr*(gain[ch]>>16);
	uint32_t v = mv/1000;
	uint32_t adc = (v/5)<<10;
	return adc;
	//return (((mv-vOffset[ch])*(gain[ch]>>16)))*5;
	//return ((v*5>>10)*1000)/(gain[ch]>>16)+vOffset[ch];
}


float tomV(float x, int ch){
	return 1000.0*(5.0*x/1024.0)/525.0+vOffset[ch];
}

float amp(float x){
	return x*1200.0-1.1;
}

float adc(float x){
	return x*1023.0/4.98 - 6.0;
}

float tip(float x){
	return x*0.0000160-0.00096;
}


float complete(float c){
	return (((c+13.0)/1.03)*K_tot+M_tot);
}

float inv_complete(float c){
	return ((c-M_tot)/K_tot)*1.03-13.0;
}

float inv_adc(float x){
	return (x+6.0)/(1023.0/4.98);
}

float inv_amp(float x){
	return (x+1.1)/1200.0;
}

float inv_tip(float x){
	return (x+0.00096)/0.0000160-6.0;
}

float code_to_c(float c){
	return inv_tip(inv_amp(inv_adc(c)))*1.03-13.0;
}

float c_to_code(float c){
	return adc(amp(tip((c+13.0)/1.03)));
}


void setupAdc(){
	ADCSRA = 1<< ADEN | 1<<ADIE | 1<<ADPS2 | 1 << ADPS1; //Enable ADC, interrupts and prescale adcclk by 64
	ADMUX = 1<<REFS0 | 1<<MUX3 | 1<<MUX2 | 1<<MUX1; //Set REFS to 01 which is the AVCC pin
	sei();
	ADCSRA |= 1<<ADSC; //Start first conversion
}

void setup()
{
	for(int ch = 0 ; ch < 4 ; ch++){
	loadChannel(ch);
	pinMode(heaterPins[ch], OUTPUT);
	digitalWrite(heaterPins[ch], LOW);
	//loadChannel(1);
	//loadChannel(2);
	//loadChannel(3);
	}
	//pinMode(ch1TempPin, INPUT);
	//pinMode(chargePumpPin, OUTPUT);
	//Serial.begin(115200);
	analogReference(DEFAULT);
	//analogWrite(chargePumpPin, 127);
	initLcd();
	//digitalWrite(7, LOW);
	pinMode(7, OUTPUT);
	setupAdc();

	pinMode(encoder0PinA, INPUT); 
	pinMode(encoder0PinB, INPUT); 
	digitalWrite(encoder0PinA, HIGH);
	digitalWrite(encoder0PinB, HIGH);

	// encoder pin on interrupt 0 (pin 2)
	attachInterrupt(0, doEncoderA, CHANGE);

	// encoder pin on interrupt 1 (pin 3)
	attachInterrupt(1, doEncoderB, CHANGE);  

	for(int ch = 0; ch < 4 ; ch++){
		ts[ch].temperature_target = 180;
		//ts[ch].adc_value_target = complete(ts[ch].temperature_target);
		ts[ch].adc_value_target = mvToAdc(celciusToMillivolts(((uint32_t)ts[ch].temperature_target)<<16), ch);
		pinMode(heaterPins[ch], OUTPUT);
	}
}

int ftoa(char *buf, float remainder, int i, int d)
{
	unsigned int cont = 1;
	unsigned int bufPos = 0;
	int mag;
	float divisor, divident, roundup;

	if(remainder < 0){
		buf[bufPos++]='-';
		remainder = - remainder;
	}

	roundup = 0.5*pow(10, 0-float(d));
	remainder += roundup;
	mag = floor(log10(fabsf(remainder)));
	mag = mag < i-1 ? i-1 : mag;
	while(cont){
		divisor = pow(10, mag);
		divident = floor(remainder/divisor);
		remainder = remainder-divident*divisor;

		if(mag == -1)
			buf[bufPos++]='.';
		buf[bufPos++]='0'+divident;
		mag = mag -1;
		if (mag < -d){
			cont = 0;
		}

	}
	return bufPos;
}


ISR(ADC_vect){
	static uint8_t ch_read = 0;
	static uint8_t samps = 0;
	static uint32_t current_value = 0;
	volatile struct tipState *ct;
	uint8_t c;
	samps++;
	if(samps > skip_samp){
		current_value += ADCL;
		current_value += (ADCH << 8);
	}
	if(samps >= over_samp+skip_samp){
		//Current value is integrated 64 times, so rescale to 16.16
		ts[ch_read].adc_value =  (current_value)<<10; 
		current_value = 0;
		samps = 0;
		ch_read++;
		ch_read = ch_read & 0x3;
		switch(ch_read){
			case 0:
				ADMUX = (ADMUX & 0xF0) | 0; break;
			case 1:
				ADMUX = (ADMUX & 0xF0) | 1; break;
			case 2:
				ADMUX = (ADMUX & 0xF0) | 6; break;
			case 3:
				ADMUX = (ADMUX & 0xF0) | 7; break;
		}
		if(ch_read == 0)
			sampCount++;
	}

	ct = &ts[0];
	for(c = 0 ; c < 4 ; c++){
		if(c == ch_read){
			switch(c){
				case 0: CLEAR_HEATER_TIP0; break;
				case 1: CLEAR_HEATER_TIP1; break;
				case 2: CLEAR_HEATER_TIP2; break;
				case 3: CLEAR_HEATER_TIP3; break;
			}
		} else {
			if(samps < ct->pwm_value){
				switch(c){
					case 0: SET_HEATER_TIP0; break;
					case 1: SET_HEATER_TIP1; break;
					case 2: SET_HEATER_TIP2; break;
					case 3: SET_HEATER_TIP3; break;
				}
			}else{
				switch(c){
					case 0: CLEAR_HEATER_TIP0; break;
					case 1: CLEAR_HEATER_TIP1; break;
					case 2: CLEAR_HEATER_TIP2; break;
					case 3: CLEAR_HEATER_TIP3; break;
				}
			}
		}
		ct++;
	}
	ADCSRA |= 1<<ADSC;
}



enum buttonAction getButtonAction(){
	static uint8_t pressCount = 0;
	static uint8_t lastButtonState = 1;
	uint8_t buttonState = digitalRead(8);
	enum buttonAction ba = NONE;

	if(buttonState == lastButtonState and buttonState == 0){
		Serial.print("pressCount ");Serial.println(pressCount);
		pressCount += 1;
	}

	if(buttonState != lastButtonState and buttonState != 0){
		if(pressCount < 2){ ba = PRESS; Serial.println("SHORT");}
		if(pressCount > 10){ ba = LONG_PRESS; Serial.println("LONG");}
	}

	if(buttonState != lastButtonState) pressCount = 0;
	lastButtonState = buttonState;
	return ba;
}

int32_t getEncoderDelta(){
	static int32_t lastPos = 0;
	int32_t delta = encoder0Pos-lastPos;
	int32_t ad = delta >> 2;
	if(ad)
		lastPos += ad<<2;
	return ad;
}

void cursorLogic( struct menuState *m){
	static uint8_t lastButtonState;
	static uint8_t start;
	int newT;
	uint8_t buttonState = digitalRead(8);
	if(m->channelIsSelected == 0){
		m->cursorChannel = (encoder0Pos >> 2)&0x03;
	} else {
		newT = start + encoder0Pos;
		if(newT < 120){
			newT = 120;
			encoder0Pos = newT-start;
		}if(newT > 400){
			newT = 400;
			encoder0Pos = newT-start;
		}
		ts[m->cursorChannel].temperature_target = newT;
	}
	if(buttonState != lastButtonState){
		if(buttonState != 0){
			if(m->channelIsSelected == 0){
				m->channelIsSelected = 1;
				start = ts[m->cursorChannel].temperature_target;
				encoder0Pos = 0;
			}else{
				//ts[m->cursorChannel].adc_value_target = complete(ts[m->cursorChannel].temperature_target);
				ts[m->cursorChannel].adc_value_target = 3; //mvToAdc(celciusToMillivolts(ts[m->cursorChannel].temperature_target<<16), m->cursorChannel);
				m->channelIsSelected = 0;
				encoder0Pos=m->cursorChannel << 2;
			}
		}
	}
	if(buttonState == lastButtonState and buttonState == 0){
		m->pressCount += 1;
	} else {
		m->pressCount = 0;
	}
	lastButtonState = buttonState;
}


void displayChannel(uint8_t ch, float setPoint, float actual, float power, struct menuState *m)
{ //                      01234567890123456789
	//const char templ[] = "0>383C(383.1C) 30.3W";
	char toPrint2[64];
	if(ch == m->cursorChannel){
		if(m->channelIsSelected == 0)
			sprintf(toPrint2, "%d>%03dC(000.0C) 00.0W", ch, int(setPoint));
		else
			sprintf(toPrint2, "%d=%03dC(000.0C) 00.0W", ch, int(setPoint));
	}
	else
		sprintf(toPrint2, "%d %03dC(000.0C) 00.0W", ch, int(setPoint));
	ftoa(toPrint2+7, actual, 3,1);
	ftoa(toPrint2+15, power, 2,1);
	ftoa(toPrint2+7, actual, 3,1);
	ftoa(toPrint2+15, power, 2,1);
	toPrint2[20]='\0';
	lcd.setCursor(0,ch);
	lcd.print(toPrint2);

}

float regulateChannel(float target, float current){
	return (target - current)*3;
}

void controlChannel(volatile struct tipState *tip){
	int32_t error = (tip->adc_value_target>>12) - (tip->adc_value>>12);
	//Serial.print("Error: "); Serial.print(error); Serial.print(" ");
	if(error < 0)
		error = 0;
	if(error > 85)
		error = 85;
	tip->pwm_value = error*1;
} 

void printControlChannel(volatile struct tipState *tip){
	Serial.print("tadc "); Serial.print(tip->adc_value_target);
	Serial.print(" cadc "); Serial.print(tip->adc_value);
	Serial.print(" pwm "); Serial.print(tip->pwm_value);
	Serial.print(" temp "); Serial.print(ts->temperature);
	Serial.println("");
}

void dprintf(uint8_t line, const char *fmt, ...){
	va_list va;
	va_start(va, fmt);
	char printBuf[21];
	vsnprintf(printBuf, 21, fmt, va);
	lcd.setCursor(0, line);
	lcd.print(printBuf);
	va_end(va);
}

void displayTs(uint8_t ch, bool selected, bool active){
	static char c;
	static uint32_t dispFilt[4] = {0, 0, 0, 0};
	static uint32_t alpha = 0.125*65536;
	static uint32_t one = 65535;
	uint32_t r = 2.1*(1<<8);
	uint32_t v = 12<<8;
	
	uint32_t power = (((uint32_t)60)*(((uint32_t)ts[ch].pwm_value)<<9));
	dispFilt[ch] = (dispFilt[ch]>>8)*((one-alpha)>>8)+(power>>8)*(alpha>>8);
	power = dispFilt[ch]>>16;
	Serial.print("Power: ");Serial.print(power);Serial.print("% ");
	if(selected){
		if(active) c = '=';
		else c ='>';
	} else c = ' ';
	if(ts[ch].temperature < 500)
	dprintf(ch, "%c %d %3uC (%3uC) %3uW         ", c, ch, ts[ch].temperature, ts[ch].temperature_target, power);
	else
	dprintf(ch, "%c %d tip  (%3uC) %3uW         ", c, ch, ts[ch].temperature_target, power);
	//dprintf(ch, "%c %d % 5d(% 3d)           ", c, 3, 4, 5);
}

void mainMenu(enum buttonAction ba, int32_t ed){
	static bool active = false;
	static int8_t selected=0;

	if(ba == PRESS) active = not active;

	if(not active){
		selected = clamp(0, selected+ed, 3);
	}

	if(active){
		ts[selected].temperature_target = clamp(180, ts[selected].temperature_target+ed, 450);
		//Serial.print(" t "); Serial.print(ts[selected].temperature_target);
		//ts[selected].adc_value_target = mvToAdc(celciusToMillivolts(ts[selected].temperature_target<<16), selected);
		ts[selected].adc_value_target = mvToAdc(celciusToMillivolts(((uint32_t) ts[selected].temperature_target)<<16), selected);
	}
	
	for(uint8_t i = 0 ; i < 4 ; i++)
		displayTs(i, selected == i , active); 
}


void serviceMenu(enum buttonAction ba, int32_t ed){
	static int16_t save;
	static int8_t ch=0;
	static bool active = false;
	static int8_t selected=0;
	char v[6];
	static char c;
	char cc;
	uint32_t mv;

	if(ba == PRESS) active = not active;

	if(not active){
		selected = clamp(0, selected+ed, 3);
	}
	if(active){
		if(selected == 0) ch = clamp(0, ch+ed, 3);
		if(selected == 1) vOffset[ch] = vOffset[ch]+(ed<<8);
		if(selected == 2) gain[ch] = gain[ch]+(ed<<16);
		if(selected == 3) save = clamp(-10, save+ed, 10);
	}

	if(active) c = '=';
	else c ='>';
	
	mv = ts[ch].adc_value;
	//Serial.print("Adc_code "); Serial.print(mv) ; Serial.print(" as mv "); Serial.print(adcTomV(mv, ch)/65536.0);
	//Serial.print(" converted back "); Serial.println(mvToAdc(adcTomV(mv, ch), ch));

	dtostrf(tomV2(mv, ch)/65536.0, 2, 3, v);
	cc = selected == 0 ? c : ' ';
	dprintf(0, "%cAdj ch %d %smV         ", cc, (int)ch, v);


	dtostrf(vOffset[ch]/65536.0, 2, 3, v);
	cc = selected == 1 ? c : ' ';
	dprintf(1, "%cOffset  %smV          ", cc, v);
	
	cc = selected == 2 ? c : ' ';
	dtostrf(((float)celciusToMillivolts(millivoltsToCelcius(adcTomV(mv,ch))))/65536.0, 3, 2, v);
	dprintf(2, "%cGain %d         ", cc, gain[ch]>>16);
	//dprintf(2, "%c %sC         ", cc, v);


	cc = selected == 3 ? c : ' ';
	dprintf(3, "%cSave/rst %d 10s/-10r", cc, save);
	if(save >= 10){
		 save = 0;
		 saveChannel(ch); 
	}
	if(save <= -10){
		save = 0;
		vOffset[ch] = 0x10000;
		gain[ch] = ((uint32_t)525)<<16;
	}

}

void menu(){
	static struct menuState ms = {0, 0, 0};
	static uint8_t mode=0;
	enum buttonAction ba;
	uint16_t ch;
	int32_t ed = getEncoderDelta();
	ba = getButtonAction();
	if(mode == 0){/*
		cursorLogic(&ms);
		for(ch = 0 ; ch < 4 ; ch ++){
			displayChannel(ch, ts[ch].temperature_target, tomV2(ts[ch].adc_value, ch)/65536.0/0.016435, ms.pressCount, &ms); 
		}*/
		mainMenu(ba, ed);
		if(ba == LONG_PRESS) mode = 1;
	} else if(mode == 1){
		if(ba == LONG_PRESS) mode = 0;
		serviceMenu(ba, ed);
	}
}

void loop()
{
	uint16_t ch;
	static long rate = 0;
	for(ch = 0 ; ch < 4 ; ch ++){
		ts[ch].temperature = float(ch); //inv_complete(ts[ch].adc_value);
		ts[ch].temperature = millivoltsToCelcius(adcTomV(ts[ch].adc_value, ch))>>16;
		controlChannel(&ts[ch]);
	}

	/*for(ch = 0 ; ch < 4 ; ch ++){
	//displayChannel(ch, int(ts[ch].temperature_target), ts[ch].temperature, (12.0*12.0/2.7)*(ts[ch].pwm_value)/128.0); 
	//displayChannel(ch, int(ts[ch].temperature_target), (float)ts[ch].temperature, (float)tomV((float)ts[ch].adc_value, ch)); 
	displayChannel(ch, ts[ch].temperature_target, ts[ch].temperature, ms.pressCount, &ms); 
	}*/
	menu();	
	delay(10);
	commandLine();
	printControlChannel(&ts[0]);
	//Serial.print("Ch0: "); Serial.print(ts[0].adc_value); 
	//Serial.print(" Enc "); Serial.print (encoder0Pos >> 2, DEC);
	//Serial.print(" Iteration time "); Serial.print(micros()-rate); 
	//Serial.print(" samps: "); Serial.print(sampCount);Serial.println("");
	rate = micros();
}

void platformSerialWrite(const char *buf, uint16_t len)
{
	Serial.write((uint8_t *)buf, len);
}

void serialEvent()
{
	while(Serial.available()){
		addCharToBuffer(Serial.read());
	}
}

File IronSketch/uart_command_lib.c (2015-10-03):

#include <avr/io.h>
#include <avr/interrupt.h>
#include <avr/pgmspace.h>
#include <string.h>
#include "uart_command_lib.h"
#include <stdlib.h>
/** Receive buffer*/
volatile char rxBuffer[RX_BUFFER_SIZE];

/** Transmit buffer*/
volatile char txBuffer[TX_BUFFER_SIZE];
/** Transmit buffer position*/
volatile int8_t txByte = -1;
/** Receive buffer position*/
volatile int8_t rxByte  = 0;

volatile uint8_t dataOverrun = 0;

const char nl[] PROGMEM = "\r\n";

void waitTransmissionIdle()
{
	while(txByte >= 0);
	while( !(UCSR0A & (1 << UDRE0)));
}

int strcmp_pn(const char *a, char *b)
{
	while(1){
		if((pgm_read_byte(a) != *b) || (*b == 0)){
			return pgm_read_byte(a)-*b;
		}
		a++;b++;
	}
}

/** Copy and reverse data from src to dst.
 * \param dst pointer to the destination
 * \param src pointer to the source
 * \param len the number of bytes to be copied
 */
void copyReverse(volatile char *dst, volatile const char *src, uint8_t len)
{
        uint8_t i;
        for(i = 0 ; i < len ; i++)
                dst[i]=src[len-i-1];
}

/** Copy and reverse data from src (in program memory) to dst.
 * \param dst pointer to the destination
 * \param src pointer to the source data, must residde in the program memory.
 * \param len the number of bytes to be copied
 */
void copyReverseP(volatile char *dst, volatile const char *src, uint8_t len)
{
        uint8_t i;
        for(i = 0 ; i < len ; i++)
                dst[i]=pgm_read_byte(src+len-i-1);
}

/** strlen for strings stored in program memory.
\param str the string for which the length should be calculated.
\return the length of the string. Not including the terminating null character.
*/
uint16_t strlenP(const char *str)
{
	uint16_t len = 0;
	while(pgm_read_byte(str++))
		len++;
	return len;
}

/** Copy data from src to dst.
 * \param dst pointer to the destination
 * \param src pointer to the source
 * \param len the number of bytes to be copied
 */
void copy(volatile char *dst, volatile const char *src, uint8_t len)
{
        uint8_t i;
        for(i = 0 ; i < len ; i++)
                *(dst++)=*(src++);
}


/** Receive interrupt for uart. Reads a byte from the register and puts it in
 * the receive buffer if there is room. Otherwise nothing is done. Does not
 * check for data overrun in the receive register/buffer.
 */
/*SIGNAL(USART_RX_vect)
{
	cli();
        static int8_t chr;
        chr = UDR0;
        if(rxByte < RX_BUFFER_SIZE){
                rxBuffer[rxByte++]=chr;
		//transmit((char*)&chr, 1);
        } else {
		PORTB |= _BV(0);
		dataOverrun = 1;
		rxByte = 0;
	}
	if(dataOverrun != 0)
		rxByte = 0;
	sei();

}*/

void addCharToBuffer(char chr)
{
        if(rxByte < RX_BUFFER_SIZE){
                rxBuffer[rxByte++]=chr;
		//transmit((char*)&chr, 1);
        } else {
		PORTB |= _BV(0);
		dataOverrun = 1;
		rxByte = 0;
	}
	if(dataOverrun != 0)
		rxByte = 0;
}

/** Transmit interrupt for uart. If there is a byte in the transmit buffer, it will be sent using transmitByte. Otherwise nothing is done.
 */
/*SIGNAL(USART_TX_vect)
{
        if(txByte>=0){
                TRANSMIT_BYTE(txBuffer[txByte--]);
	}
}*/


/** Transmit num bytes of data from msg. Transmit num bytes from from msg 
 * pointer. If num is less then the free space in the transmit buffer, 
 * num bytes data is copied from msg to the buffer and the the function 
 * returns. 
 * Othwerwise the function continously fills the buffer untill all data is 
 * in the buffer, then it returns.
 * \param msg pointer to the data to be transmitted
 * \param num number of bytes to transmit
 * \todo fix bug which causes double transmission of some characters between
 * different calls to this function.
 */
/*void transmit(const char *msg, uint16_t num)
{
        uint16_t i=0;//number of bytes xmitd
        int16_t tmp;
        while(i < num){
                //how many bytes to send in this burst?
                tmp = (num -i);
                tmp = tmp > TX_BUFFER_SIZE ? TX_BUFFER_SIZE : tmp;
                //wait for earlier xmit to finnish
                while(txByte>=0);
                //copy to tx-buffer
		cli();
                copyReverse(txBuffer, msg+i,(unsigned) tmp);
                //tmp more bytes has been sent
                i+=tmp;
                //copyReverse(txBuffer, "1234567890123456", 16);
                //txByte = 15;
                txByte = tmp-1;
                TRANSMIT_BYTE(txBuffer[txByte--]);
		sei();
        }
}*/

void transmit(const char *msg, uint16_t num)
{
    platformSerialWrite(msg, num);
    //int i;
    //for(i = num ; i < num ; i++)
    //    TRANSMIT_BYTE(i+'0');
}

/** same as the transmit function but for when the msg data is stired
 * in program memory.
 * \param msg pointer to data in in program memory to be transmitted.
 * \param num number of bytes to transmit
*/
/*void transmitP(const char *msg, uint16_t num)
{
        uint16_t i=0;//number of bytes xmitd
        int16_t tmp;
        while(i < num){
                //how many bytes to send in this burst?
                tmp = (num -i);
                tmp = tmp > TX_BUFFER_SIZE ? TX_BUFFER_SIZE : tmp;
                //wait for earlier xmit to finnish
                while(txByte>=0);
                //copy to tx-buffer
		cli();
                copyReverseP(txBuffer, msg+i,(unsigned) tmp);
                //tmp more bytes has been sent
                i+=tmp;
                txByte = tmp-1;
                TRANSMIT_BYTE(txBuffer[txByte--]);
		sei();
        }
}*/

void transmitP(const char *msg, uint16_t num)
{
    char a[1];
    for(; num > 0 ; num--){
        a[0] = pgm_read_byte(msg++);
        platformSerialWrite(a,1);
    }
}
/** Transmit a string, determines string length by looking for null character
 * and then calls transmit the string.
 * \param msg poiner to the first byte in the string to be transmitted.
 */
void transmitString(const char *msg)
{
        transmit(msg, strlen(msg));
}

/** Transmit a string, determines string length by looking for null character
 * and then calls transmit the string. The string must be stored in program
 * memory
 * \param msg poiner to the first byte in the string to be transmitted.
 * The string must be located in program memory.
 */
void transmitStringP(const char *msg)
{
        transmitP(msg, strlenP(msg));
}

/** initialize the Universal serial asynchronous receiver/transcaiver.
 * 19200 bps 8N1, with both transmit and receive interrupts
 */
void initUsart()
{
	DDRD &= 0xFE;
	DDRD |= 0x02;
        DDRD = 2;
	UBRR0H = 0;
        UBRR0L = 35;
        //UBRR0L = 36*2+1;//576/8;
        //UBRR0 = 576/8;
        UCSR0B = _BV(RXEN0)  | _BV(RXCIE0) | _BV(TXCIE0) | _BV(TXEN0);
        UCSR0C = _BV(UCSZ00) | _BV(UCSZ01) ;
	sei();
}

/** Transmit an integer as its decimal representation in ascii.
 * The integer number must fit in 7 bytes.
 * \param i the integer to be transmitted as ascii text.
*/
void transmitInt(const int32_t i)
{
	static char m[16];
	ltoa(i, m, 10);
	transmitString(m);
}
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

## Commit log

2016-03-20 Reorganized arduinofiles and added working version och schematic
    [CorboIron.kicad_pcb, CorboIron.sch]
2016-03-20 Started PCB
    [CorboIron.kicad_pcb, CorboIron.sch]
2016-03-20 Tried to add footprints
    [CorboIron.kicad_pcb]
2016-03-20 Started placing componets
    [CorboIron.kicad_pcb, CorboIron.sch]
2016-03-24 Started pretty version
    [CorboIron.kicad_pcb, CorboIron.sch, _saved_CorboIron.sch]
2016-03-25 Completely routed but not pretty or functional, need wider traces for the heater currents!
    [CorboIron.kicad_pcb, CorboIron.sch]
2016-03-25 Some via stitching
    [CorboIron.kicad_pcb]
2016-03-25 perhaps usable
    [CorboIron.kicad_pcb]
2016-03-26 Added gerber and drl files
    [CorboIron-B.Cu.gbr, CorboIron-B.SilkS.gbr, CorboIron-F.Cu.gbr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]
2016-03-26 Added box
    [Box.scad]
2016-03-27 Added pulldown resistors for opamp logic started placeing refdes and values on silkscreen
    [CorboIron.kicad_pcb, CorboIron.sch]
2016-03-27 Tidying up of silkscreen
    [CorboIron.kicad_pcb]
2016-03-27 Added plots
    [CorboIron.kicad_pcb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]
2016-03-28 Added descriptive text in silk
    [CorboIron.kicad_pcb]
2016-03-29 Minor changes
    [CorboIron.kicad_pcb]
2016-04-18 Checked footprints, design should be ready for production
    [Box.scad, CorboIron.kicad_pcb, CorboIron.sch]
2016-04-19 Added files sent to production
    [CorboIron-B.Mask.gbs, CorboIron-F.Mask.gts, CorboIron.GBL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]
2016-05-06 Started adaptations for new board
2016-06-02 Started work on standing box, metcal-ish
    [StandingBox.scad]
2016-06-06 More work on the standing box
    [StandingBox.scad]
2016-06-26 Added solder iron stand
    [StandingBox.scad]
2016-07-14 dont remember exactly :)
    [CorboIron.sch, StandingBox.scad]
2016-07-16 Started work on regulator
2016-09-24 Made box out of separate panels to simplify printing
    [StandingBox.scad, StandingBoxPanels.scad]
2016-10-01 Started working on the pen
    [StandingBoxPanels.scad]
2017-07-21 Temperature is somewhat sane, about 5 C error between 150 and 350 C but the ADC used seems to be not perfect so this probably only works for this individual hardware
    [IronSketch.ino]
2017-07-23 Untested code , but started moving sampling and pwm to an interrupt
2018-01-10 Reverted schematic
    [CorboIron.sch]
2018-01-27 Reference point if i decide to go back from more fixed point instead of floating point
    [IronSketch.ino]
2018-08-16 Minor adjustments
    [StandingBoxPanels.scad]
